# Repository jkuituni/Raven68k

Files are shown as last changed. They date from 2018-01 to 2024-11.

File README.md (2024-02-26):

# Raven68k
Raven 68k is a simple Motorola 68k family based single board computer. The machine will serve as a learning tool
for building a 68k based machines for learning on how to interface various chips and add on expansions for the
architecture. It is also aimed to be a platform for learning on how to write firmware and operating system level
code and how to implement the required logic in VHDL code to tie in all of the functionality required. We are
interested on eventually getting Linux up and running on the hardware as the Linux/m68k is still maintained and
it supports many of the basic building blocks.

The project will be documented to a blog along with datasheets of all the components used.

## Folder Structure
*datasheets/* -- The datasheets of the components used in various revisions of Raven.

*firmware/* - ROM images to boot and initialize the system.

*software/* - S68 programs that can be loaded from the firmware. Many of these are built with [EASy68k](http://easy68k.com/).

*hardware/* -- KiCAD schematics and other files as well as VHDL code for the CPLD are located here.

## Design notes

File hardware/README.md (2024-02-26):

# Raven68k - Hardware

Hardware description for the various revisions are contained with-in here. Each directory contains the KiCAD schematic files as well as other KiCAD files. You will also find revision specific Xilinx VHDL files required for programing the CPLD chips under the directories.

## Folder structure

*prototype/* - Prototype schematics.

*rev1/* - Files for revision 1.

*rev2/* - Files for revision 2.

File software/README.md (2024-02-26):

# Raven68k - Software

Software for Raven. Common for all Raven revisions.

## Folder structure

*ehbasic/* - Port of Lee Davison's excellent EHBASIC for Raven.

*interrupt-monitor/* - Interrupt driven machine language monitor by Hayden Kroepfl ported to run on Raven.

*polling-monitor/* - A polling version of the above.

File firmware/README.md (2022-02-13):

# How to compile
### The short, short version

 1. Get `docker`. Actually, get `nerdctl` or `podman` instead if you know what you are doing.
 2. Pull the compiler container

> docker pull mrszb/m68kcross:11.2

3. From this directory, start the container and mount this directory as `/src`

> docker run --rm -it -v ${PWD}:/src mrszb/m68kcross:11.2 bash

The source is now mounted to the `/src` folder.  To compile:

> cd /src
> make clean
> make

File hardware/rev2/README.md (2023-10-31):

# Raven68k - Revision 2

The specifications for the revision 2 version of Raven68k are as follows:

- Motorola 68010 CPU
- 64kB of EEPROM for bootstrapping the Linux
- Single 72pin SIMM socket for RAM. Upto 16MB supported.
- Motorola 68681 DUART with USB adapter on one UART and max233 on other
- Dallas DS12887A Real Time Clock
- Xilinx XC9572XL CPLD as system glue logic.

The revision 2 of Raven is intended as a minor improvement and bug fix version. Most likely no further revisions will be made and work will continue in a higher spec follow-up computer.

## Folder structure

*schematic/* - KiCad schematics for this revision.

*vhdl/* - The VHDL source for the CPLD that manages most of the TTL logic present and implements the DRAM controller. 

*xilinx/* - The ISE WebPack (14.2) project itself, which targets a QFP100 XC9572XL.

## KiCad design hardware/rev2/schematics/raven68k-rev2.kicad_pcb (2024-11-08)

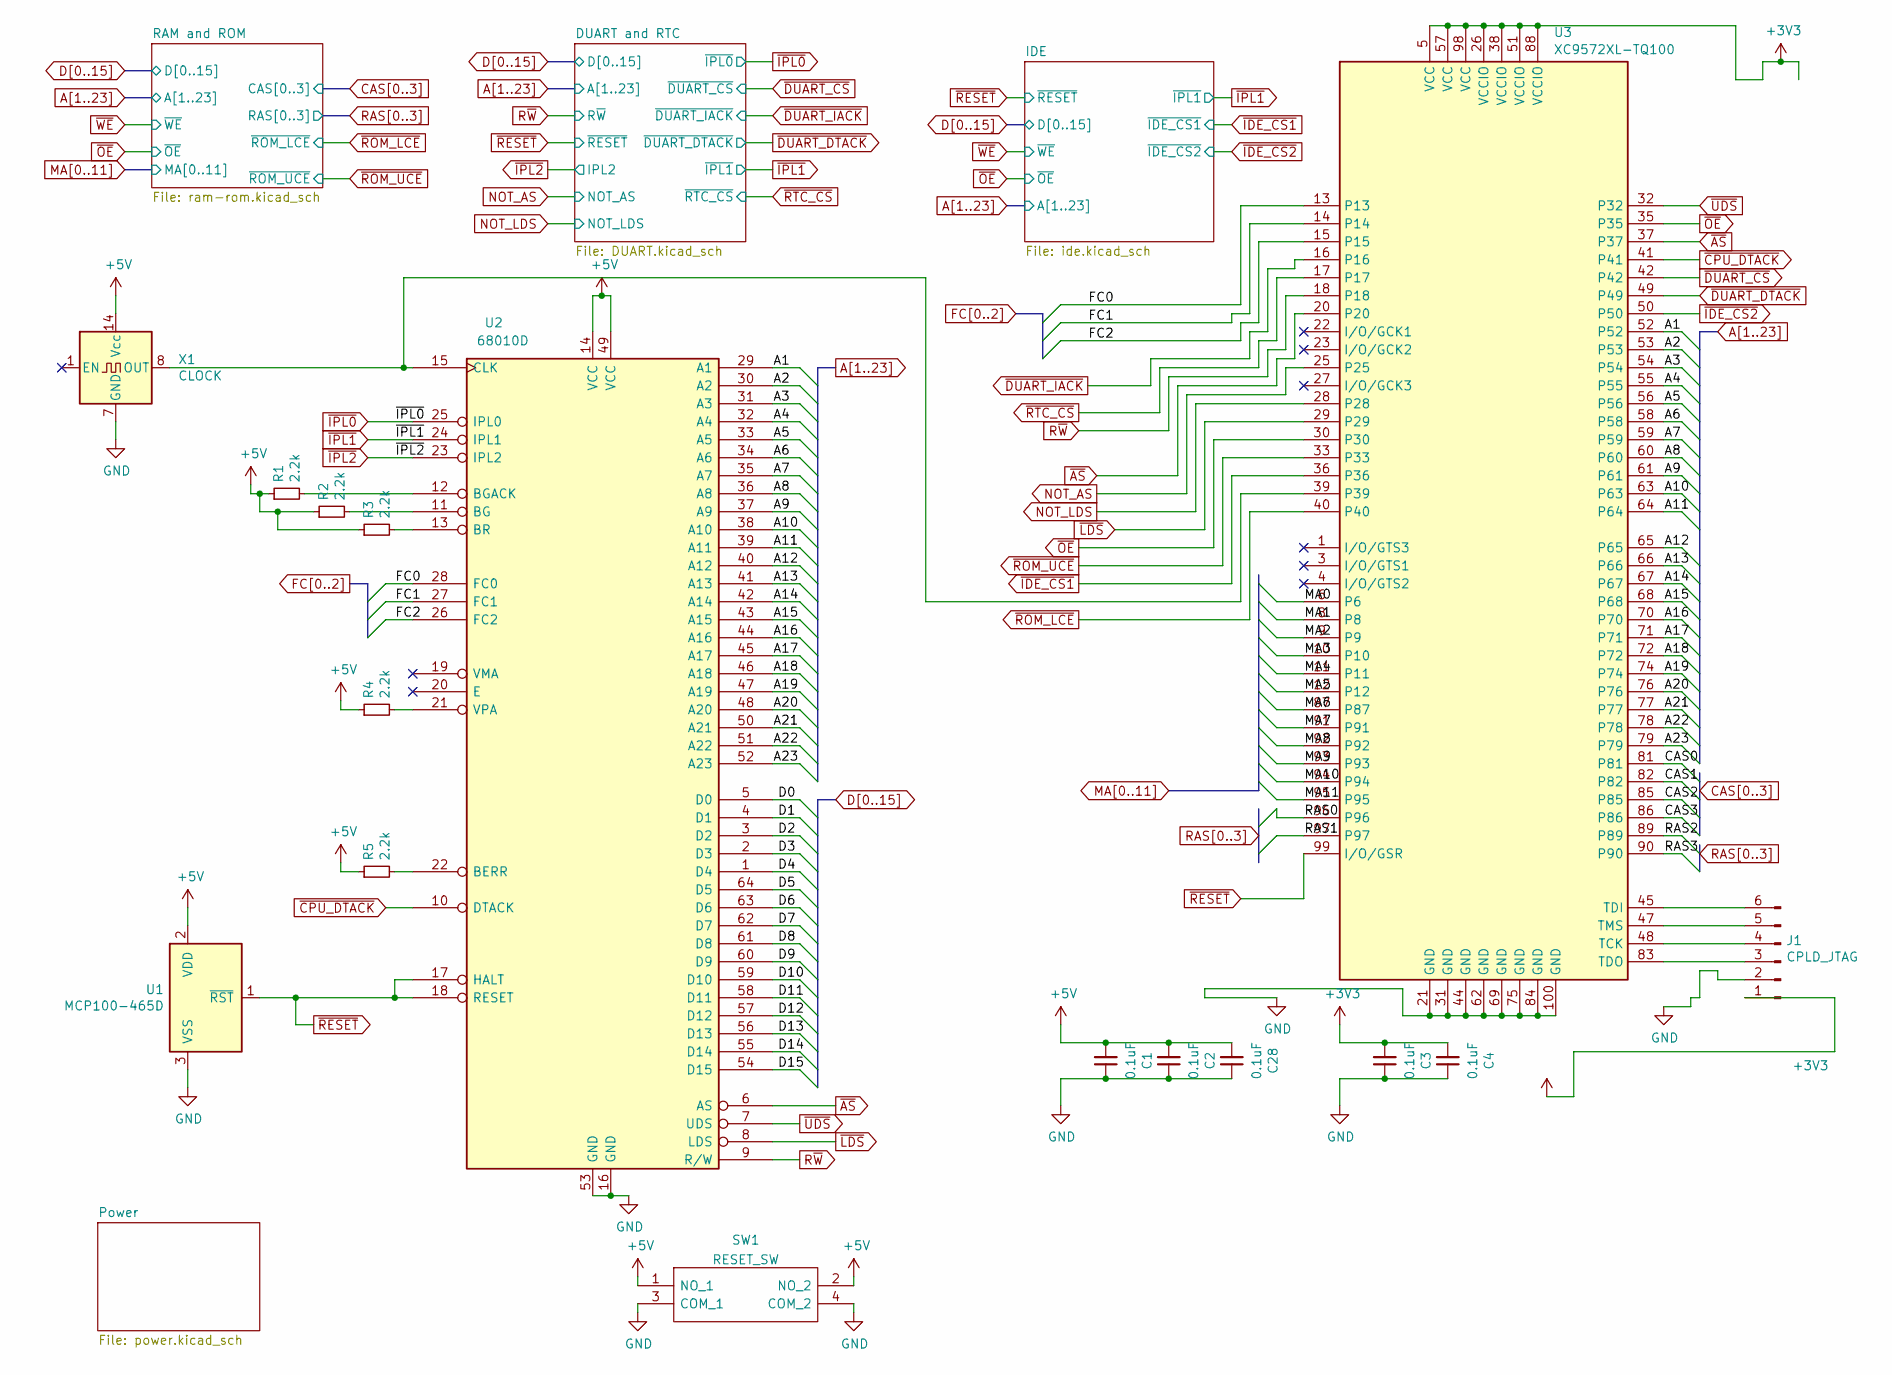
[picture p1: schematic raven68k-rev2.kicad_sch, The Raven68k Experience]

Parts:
C1, C2, C3, C4, C28: 0.1uF; C_1206_3216Metric_Pad1.33x1.80mm_HandSolder; LCSC C24497
J1: CPLD_JTAG; PinHeader_1x06_P2.54mm_Vertical
R1, R2, R3, R4, R5: 2.2k; R_1206_3216Metric_Pad1.30x1.75mm_HandSolder
SW1: RESET_SW; TS0266170BK160SCRD; Manufacturer_Part_Number TS02-66-170-BK-160-SCR-D
U1: MCP100-465D; TO-92L_HandSolder
U2: 68010D; DIP-64_W25.4mm_Socket_LongPads
U3: XC9572XL-TQ100; TQFP-100_14x14mm_P0.5mm
X1: CLOCK; Oscillator_DIP-14_LargePads

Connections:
+3V3: C3.2, C4.2, J1.1, U3.5 (VCC), U3.26 (VCCIO), U3.38 (VCCIO), U3.51 (VCCIO), U3.57 (VCC), U3.88 (VCCIO), U3.98 (VCC); also elsewhere on the board
+5V: C1.2, C2.2, C28.2, R1.1, R2.1, R3.1, R4.1, R5.1, SW1.1 (NO_1), SW1.2 (NO_2), U1.2 (VDD), U2.14 (VCC), U2.49 (VCC), X1.14 (Vcc); also elsewhere on the board
A1: U2.29 (A1), U3.52; also elsewhere on the board
A2: U2.30 (A2), U3.53; also elsewhere on the board
A3: U2.31 (A3), U3.54; also elsewhere on the board
A4: U2.32 (A4), U3.55; also elsewhere on the board
A5: U2.33 (A5), U3.56; also elsewhere on the board
A6: U2.34 (A6), U3.58; also elsewhere on the board
A7: U2.35 (A7), U3.59; also elsewhere on the board
A8: U2.36 (A8), U3.60; also elsewhere on the board
A9: U2.37 (A9), U3.61; also elsewhere on the board
A10: U2.38 (A10), U3.63; also elsewhere on the board
A11: U2.39 (A11), U3.64; also elsewhere on the board
A12: U2.40 (A12), U3.65; also elsewhere on the board
A13: U2.41 (A13), U3.66; also elsewhere on the board
A14: U2.42 (A14), U3.67; also elsewhere on the board
A15: U2.43 (A15), U3.68; also elsewhere on the board
A16: U2.44 (A16), U3.70
A17: U2.45 (A17), U3.71
A18: U2.46 (A18), U3.72
A19: U2.47 (A19), U3.74
A20: U2.48 (A20), U3.76
A21: U2.50 (A21), U3.77
A22: U2.51 (A22), U3.78
A23: U2.52 (A23), U3.79
CAS0: U3.81; also elsewhere on the board
CAS1: U3.82; also elsewhere on the board
CAS2: U3.85; also elsewhere on the board
CAS3: U3.86; also elsewhere on the board
D0: U2.5 (D0); also elsewhere on the board
D1: U2.4 (D1); also elsewhere on the board
D2: U2.3 (D2); also elsewhere on the board
D3: U2.2 (D3); also elsewhere on the board
D4: U2.1 (D4); also elsewhere on the board
D5: U2.64 (D5); also elsewhere on the board
D6: U2.63 (D6); also elsewhere on the board
D7: U2.62 (D7); also elsewhere on the board
D8: U2.61 (D8); also elsewhere on the board
D9: U2.60 (D9); also elsewhere on the board
D10: U2.59 (D10); also elsewhere on the board
D11: U2.58 (D11); also elsewhere on the board
D12: U2.57 (D12); also elsewhere on the board
D13: U2.56 (D13); also elsewhere on the board
D14: U2.55 (D14); also elsewhere on the board
D15: U2.54 (D15); also elsewhere on the board
FC0: U2.28 (FC0), U3.13
FC1: U2.27 (FC1), U3.14
FC2: U2.26 (FC2), U3.15
GND: C1.1, C2.1, C3.1, C4.1, C28.1, J1.2, SW1.3 (COM_1), SW1.4 (COM_2), U1.3 (VSS), U2.16 (GND), U2.53 (GND), U3.21 (GND), U3.31 (GND), U3.44 (GND), U3.62 (GND), U3.69 (GND), U3.75 (GND), U3.84 (GND), U3.100 (GND), X1.7 (GND); also elsewhere on the board
MA0: U3.6; also elsewhere on the board
MA1: U3.8; also elsewhere on the board
MA2: U3.9; also elsewhere on the board
MA3: U3.10; also elsewhere on the board
MA4: U3.11; also elsewhere on the board
MA5: U3.12; also elsewhere on the board
MA6: U3.87; also elsewhere on the board
MA7: U3.91; also elsewhere on the board
MA8: U3.92; also elsewhere on the board
MA9: U3.93; also elsewhere on the board
MA10: U3.94; also elsewhere on the board
MA11: U3.95; also elsewhere on the board
NOT_AS: U3.25; also elsewhere on the board
NOT_LDS: U3.28; also elsewhere on the board
unnamed: J1.3, U3.83 (TDO)
unnamed: J1.4, U3.48 (TCK)
unnamed: J1.5, U3.47 (TMS)
unnamed: J1.6, U3.45 (TDI)
unnamed: R5.2, U2.22 (BERR)
unnamed: R2.2, U2.11 (BG)
unnamed: R1.2, U2.12 (BGACK)
unnamed: R3.2, U2.13 (BR)
unnamed: U2.15 (CLK), U3.39, X1.8 (OUT)
unnamed: R4.2, U2.21 (VPA)
RAS0: U3.96; also elsewhere on the board
RAS1: U3.97; also elsewhere on the board
RAS2: U3.89; also elsewhere on the board
RAS3: U3.90; also elsewhere on the board
R~W: U2.9 (R/W), U3.18; also elsewhere on the board
~AS: U2.6 (AS), U3.20, U3.37
~CPU_DTACK: U2.10 (DTACK), U3.41
~DUART_CS: U3.42; also elsewhere on the board
~DUART_DTACK: U3.49; also elsewhere on the board
~DUART_IACK: U3.16; also elsewhere on the board
~IDE_CS1: U3.36; also elsewhere on the board
~IDE_CS2: U3.50; also elsewhere on the board
~IPL0: U2.25 (IPL0); also elsewhere on the board
~IPL1: U2.24 (IPL1); also elsewhere on the board
~IPL2: U2.23 (IPL2); also elsewhere on the board
~LDS: U2.8 (LDS), U3.29
~OE: U3.30, U3.35; also elsewhere on the board
~RESET: U1.1 (~RST), U2.17 (HALT), U2.18 (RESET), U3.99 (I/O/GSR); also elsewhere on the board
~ROM_LCE: U3.40; also elsewhere on the board
~ROM_UCE: U3.33; also elsewhere on the board
~RTC_CS: U3.17; also elsewhere on the board
~UDS: U2.7 (UDS), U3.32

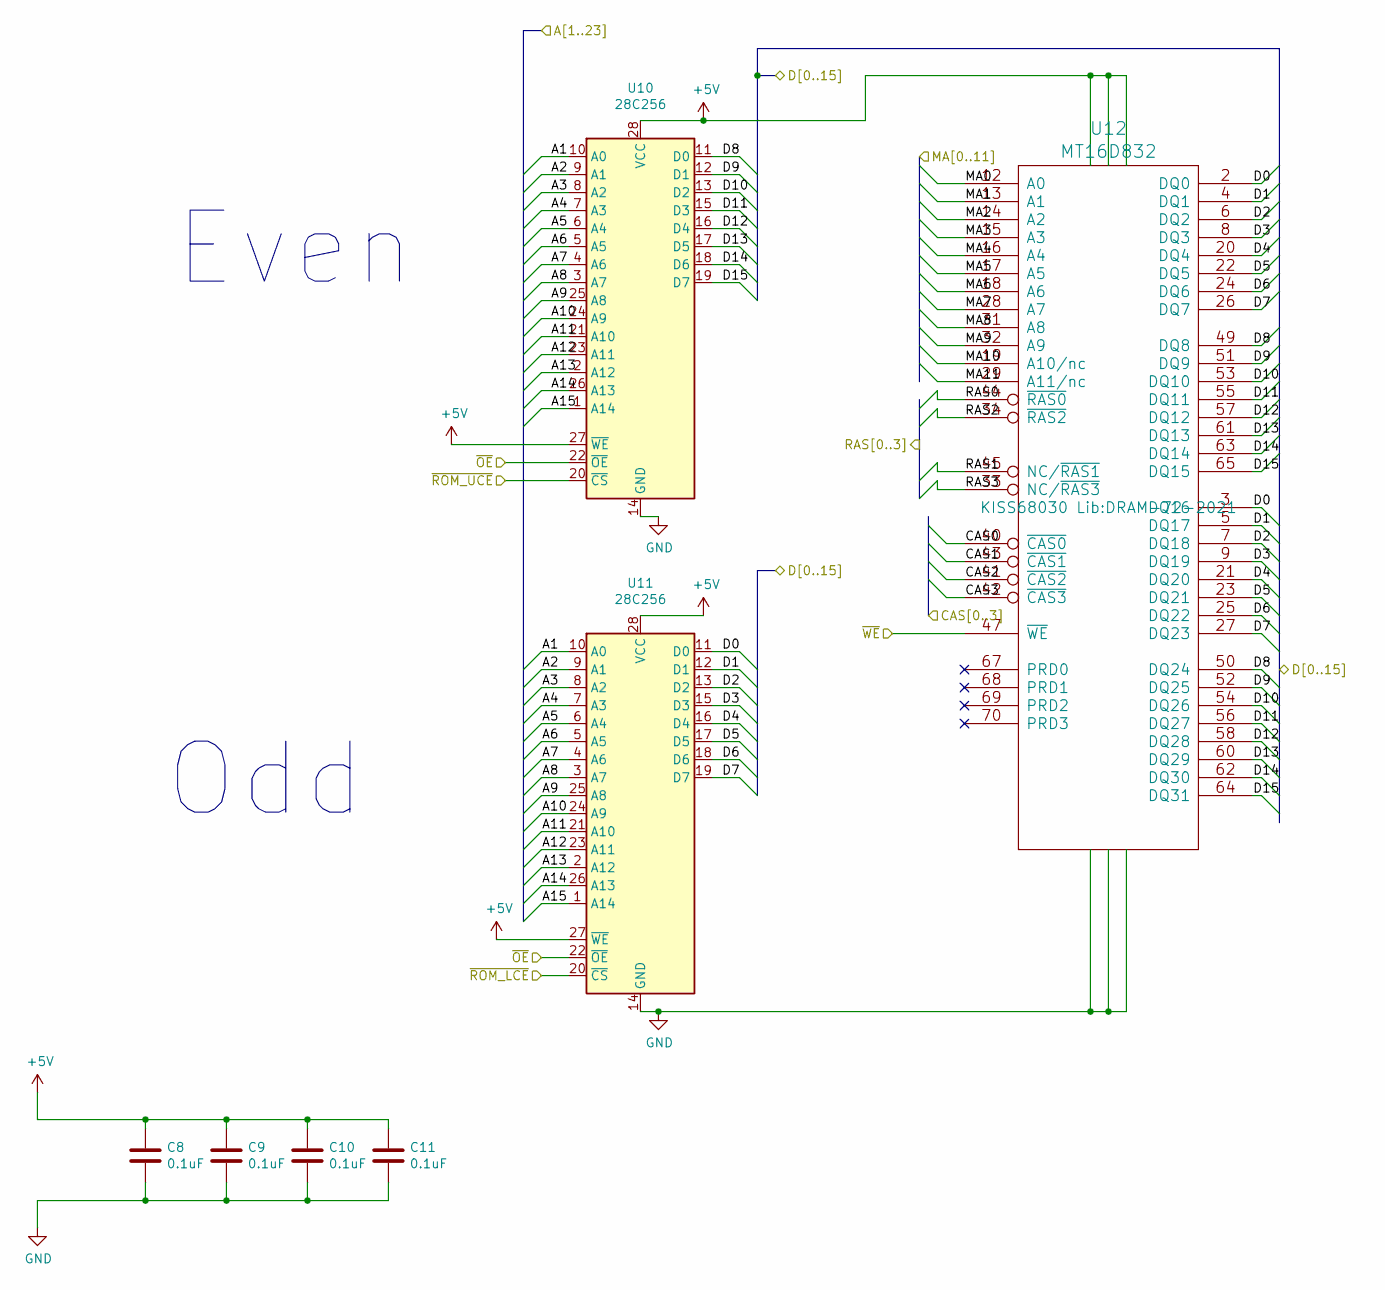
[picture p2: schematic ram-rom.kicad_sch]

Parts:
C8, C9, C10, C11: 0.1uF; C_1206_3216Metric_Pad1.33x1.80mm_HandSolder; LCSC C24497
U10, U11: 28C256; DIP-28_W15.24mm_Socket_LongPads
U12: MT16D832; DRAM-72-2021

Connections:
+5V: C8.1, C9.1, C10.1, C11.1, U10.27 (~WE), U10.28 (VCC), U11.27 (~WE), U11.28 (VCC), U12.10 (VCC), U12.30 (VCC), U12.59 (VCC); also elsewhere on the board
A1: U10.10 (A0), U11.10 (A0); also elsewhere on the board
A2: U10.9 (A1), U11.9 (A1); also elsewhere on the board
A3: U10.8 (A2), U11.8 (A2); also elsewhere on the board
A4: U10.7 (A3), U11.7 (A3); also elsewhere on the board
A5: U10.6 (A4), U11.6 (A4); also elsewhere on the board
A6: U10.5 (A5), U11.5 (A5); also elsewhere on the board
A7: U10.4 (A6), U11.4 (A6); also elsewhere on the board
A8: U10.3 (A7), U11.3 (A7); also elsewhere on the board
A9: U10.25 (A8), U11.25 (A8); also elsewhere on the board
A10: U10.24 (A9), U11.24 (A9); also elsewhere on the board
A11: U10.21 (A10), U11.21 (A10); also elsewhere on the board
A12: U10.23 (A11), U11.23 (A11); also elsewhere on the board
A13: U10.2 (A12), U11.2 (A12); also elsewhere on the board
A14: U10.26 (A13), U11.26 (A13); also elsewhere on the board
A15: U10.1 (A14), U11.1 (A14); also elsewhere on the board
CAS0: U12.40 (~CAS0); also elsewhere on the board
CAS1: U12.43 (~CAS1); also elsewhere on the board
CAS2: U12.41 (~CAS2); also elsewhere on the board
CAS3: U12.42 (~CAS3); also elsewhere on the board
D0: U11.11 (D0), U12.2 (DQ0), U12.3 (DQ16); also elsewhere on the board
D1: U11.12 (D1), U12.4 (DQ1), U12.5 (DQ17); also elsewhere on the board
D2: U11.13 (D2), U12.6 (DQ2), U12.7 (DQ18); also elsewhere on the board
D3: U11.15 (D3), U12.8 (DQ3), U12.9 (DQ19); also elsewhere on the board
D4: U11.16 (D4), U12.20 (DQ4), U12.21 (DQ20); also elsewhere on the board
D5: U11.17 (D5), U12.22 (DQ5), U12.23 (DQ21); also elsewhere on the board
D6: U11.18 (D6), U12.24 (DQ6), U12.25 (DQ22); also elsewhere on the board
D7: U11.19 (D7), U12.26 (DQ7), U12.27 (DQ23); also elsewhere on the board
D8: U10.11 (D0), U12.49 (DQ8), U12.50 (DQ24); also elsewhere on the board
D9: U10.12 (D1), U12.51 (DQ9), U12.52 (DQ25); also elsewhere on the board
D10: U10.13 (D2), U12.53 (DQ10), U12.54 (DQ26); also elsewhere on the board
D11: U10.15 (D3), U12.55 (DQ11), U12.56 (DQ27); also elsewhere on the board
D12: U10.16 (D4), U12.57 (DQ12), U12.58 (DQ28); also elsewhere on the board
D13: U10.17 (D5), U12.60 (DQ29), U12.61 (DQ13); also elsewhere on the board
D14: U10.18 (D6), U12.62 (DQ30), U12.63 (DQ14); also elsewhere on the board
D15: U10.19 (D7), U12.64 (DQ31), U12.65 (DQ15); also elsewhere on the board
GND: C8.2, C9.2, C10.2, C11.2, U10.14 (GND), U11.14 (GND), U12.1 (GND), U12.39 (GND), U12.72 (GND); also elsewhere on the board
MA0: U12.12 (A0); also elsewhere on the board
MA1: U12.13 (A1); also elsewhere on the board
MA2: U12.14 (A2); also elsewhere on the board
MA3: U12.15 (A3); also elsewhere on the board
MA4: U12.16 (A4); also elsewhere on the board
MA5: U12.17 (A5); also elsewhere on the board
MA6: U12.18 (A6); also elsewhere on the board
MA7: U12.28 (A7); also elsewhere on the board
MA8: U12.31 (A8); also elsewhere on the board
MA9: U12.32 (A9); also elsewhere on the board
MA10: U12.19 (A10/nc); also elsewhere on the board
MA11: U12.29 (A11/nc); also elsewhere on the board
RAS0: U12.44 (~RAS0); also elsewhere on the board
RAS1: U12.45 (NC/~RAS1); also elsewhere on the board
RAS2: U12.34 (~RAS2); also elsewhere on the board
RAS3: U12.33 (NC/~RAS3); also elsewhere on the board
~OE: U10.22 (~OE), U11.22 (~OE); also elsewhere on the board
~ROM_LCE: U11.20 (~CS); also elsewhere on the board
~ROM_UCE: U10.20 (~CS); also elsewhere on the board
~WE: U12.47 (~WE); also elsewhere on the board

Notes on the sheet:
Even
Odd

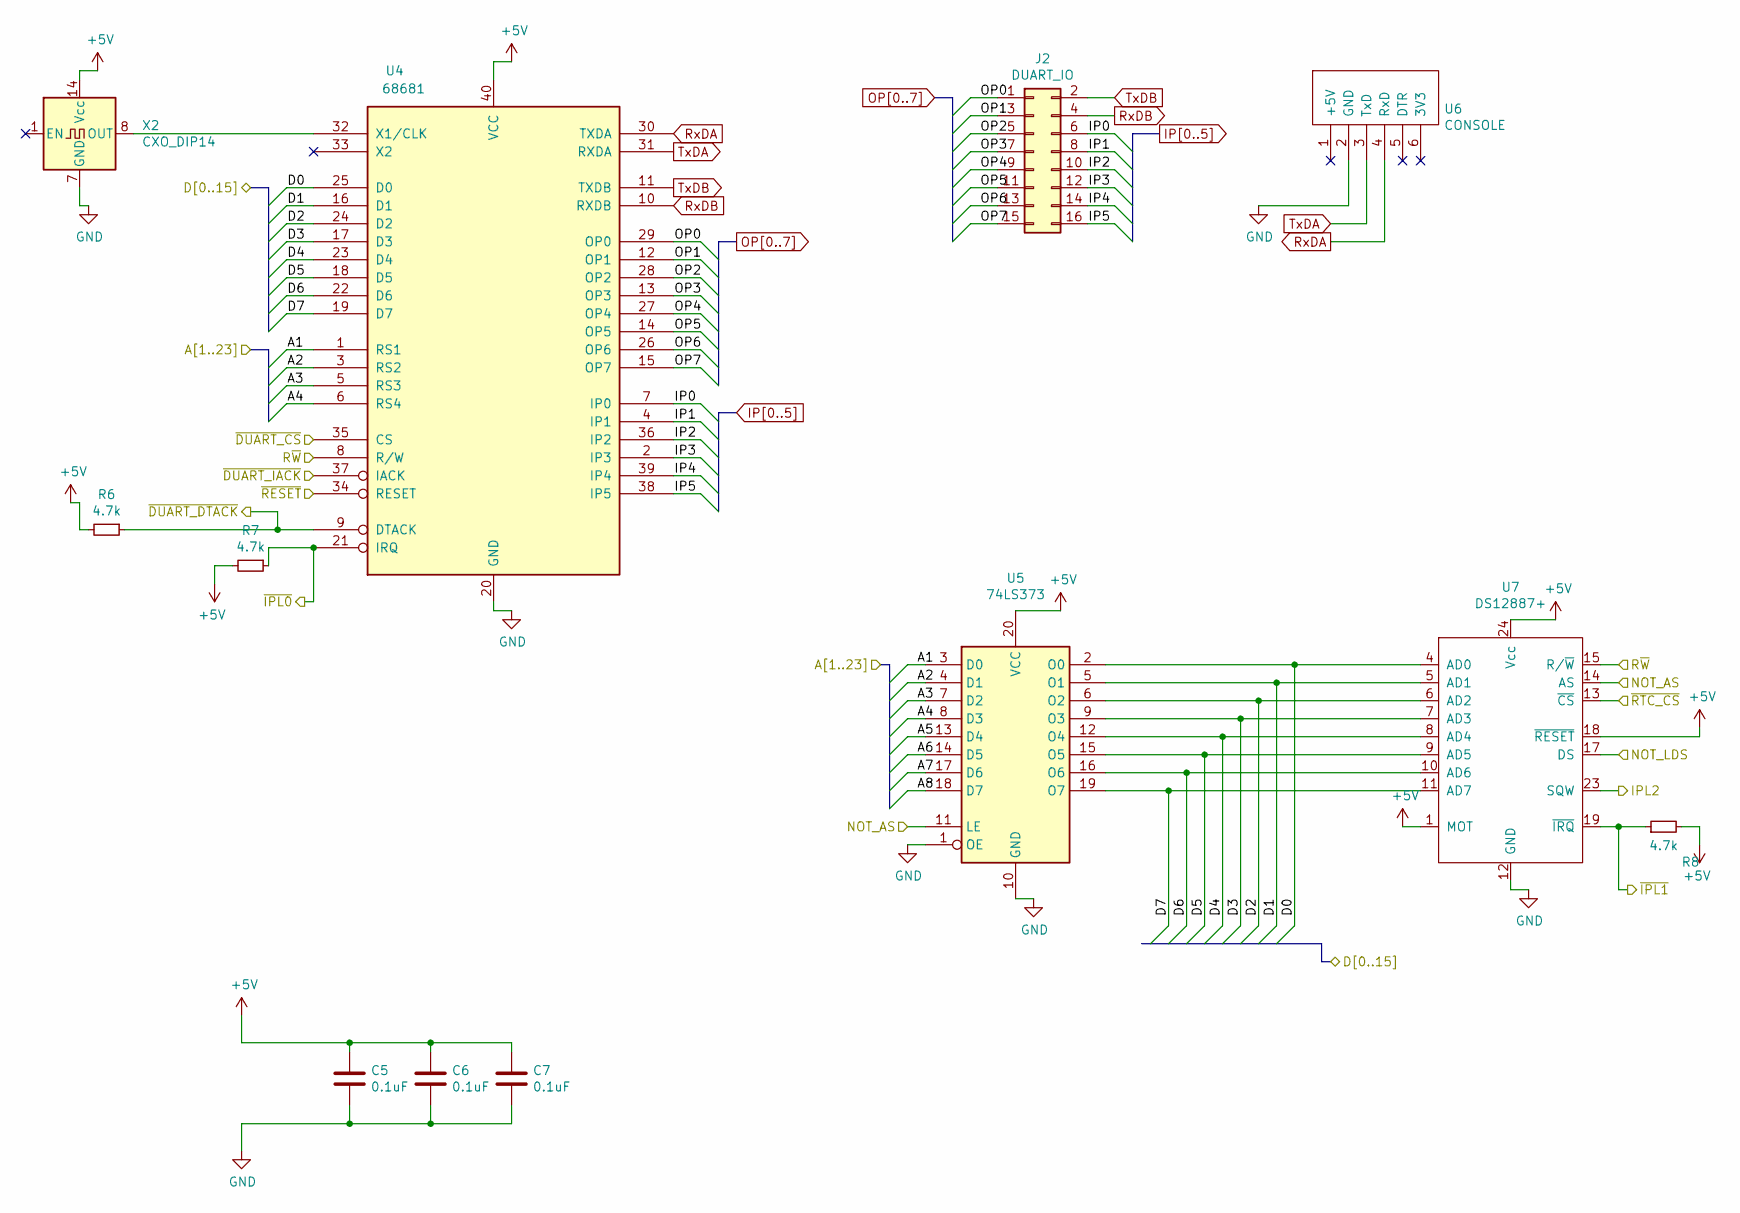
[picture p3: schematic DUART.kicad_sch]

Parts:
C5, C6, C7: 0.1uF; C_1206_3216Metric_Pad1.33x1.80mm_HandSolder; LCSC C24497
J2: DUART_IO; PinHeader_2x08_P2.54mm_Vertical
R6, R7, R8: 4.7k; R_1206_3216Metric_Pad1.30x1.75mm_HandSolder
U4: 68681; DIP-40_W25.4mm_Socket_LongPads
U5: 74LS373; DIP-20_W7.62mm_Socket_LongPads
U6: CONSOLE; PinHeader_1x06_P2.54mm_Vertical
U7: DS12887+; DIP-24_W15.24mm_Socket_LongPads
X2: CXO_DIP14; Oscillator_DIP-14_LargePads

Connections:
+5V: C5.1, C6.1, C7.1, R6.2, R7.2, R8.2, U4.40 (VCC), U5.20 (VCC), U7.1 (MOT), U7.18 (~RESET), U7.24 (Vcc), X2.14 (Vcc); also elsewhere on the board
A1: U4.1 (RS1), U5.3 (D0); also elsewhere on the board
A2: U4.3 (RS2), U5.4 (D1); also elsewhere on the board
A3: U4.5 (RS3), U5.7 (D2); also elsewhere on the board
A4: U4.6 (RS4), U5.8 (D3); also elsewhere on the board
A5: U5.13 (D4); also elsewhere on the board
A6: U5.14 (D5); also elsewhere on the board
A7: U5.17 (D6); also elsewhere on the board
A8: U5.18 (D7); also elsewhere on the board
D0: U4.25 (D0), U5.2 (O0), U7.4 (AD0); also elsewhere on the board
D1: U4.16 (D1), U5.5 (O1), U7.5 (AD1); also elsewhere on the board
D2: U4.24 (D2), U5.6 (O2), U7.6 (AD2); also elsewhere on the board
D3: U4.17 (D3), U5.9 (O3), U7.7 (AD3); also elsewhere on the board
D4: U4.23 (D4), U5.12 (O4), U7.8 (AD4); also elsewhere on the board
D5: U4.18 (D5), U5.15 (O5), U7.9 (AD5); also elsewhere on the board
D6: U4.22 (D6), U5.16 (O6), U7.10 (AD6); also elsewhere on the board
D7: U4.19 (D7), U5.19 (O7), U7.11 (AD7); also elsewhere on the board
GND: C5.2, C6.2, C7.2, U4.20 (GND), U5.1 (OE), U5.10 (GND), U6.2 (GND), U7.12 (GND), X2.7 (GND); also elsewhere on the board
IP0: J2.6, U4.7 (IP0)
IP1: J2.8, U4.4 (IP1)
IP2: J2.10, U4.36 (IP2)
IP3: J2.12, U4.2 (IP3)
IP4: J2.14, U4.39 (IP4)
IP5: J2.16, U4.38 (IP5)
NOT_AS: U5.11 (LE), U7.14 (AS); also elsewhere on the board
NOT_LDS: U7.17 (DS); also elsewhere on the board
unnamed: U4.32 (X1/CLK), X2.8 (OUT)
OP0: J2.1, U4.29 (OP0)
OP1: J2.3, U4.12 (OP1)
OP2: J2.5, U4.28 (OP2)
OP3: J2.7, U4.13 (OP3)
OP4: J2.9, U4.27 (OP4)
OP5: J2.11, U4.14 (OP5)
OP6: J2.13, U4.26 (OP6)
OP7: J2.15, U4.15 (OP7)
RxDA: U4.30 (TXDA), U6.4 (RxD)
RxDB: J2.4, U4.10 (RXDB)
R~W: U4.8 (R/W), U7.15 (R/~W); also elsewhere on the board
TxDA: U4.31 (RXDA), U6.3 (TxD)
TxDB: J2.2, U4.11 (TXDB)
~DUART_CS: U4.35 (CS); also elsewhere on the board
~DUART_DTACK: R6.1, U4.9 (DTACK); also elsewhere on the board
~DUART_IACK: U4.37 (IACK); also elsewhere on the board
~IPL0: R7.1, U4.21 (IRQ); also elsewhere on the board
~IPL1: R8.1, U7.19 (~IRQ); also elsewhere on the board
~IPL2: U7.23 (SQW); also elsewhere on the board
~RESET: U4.34 (RESET); also elsewhere on the board
~RTC_CS: U7.13 (~CS); also elsewhere on the board

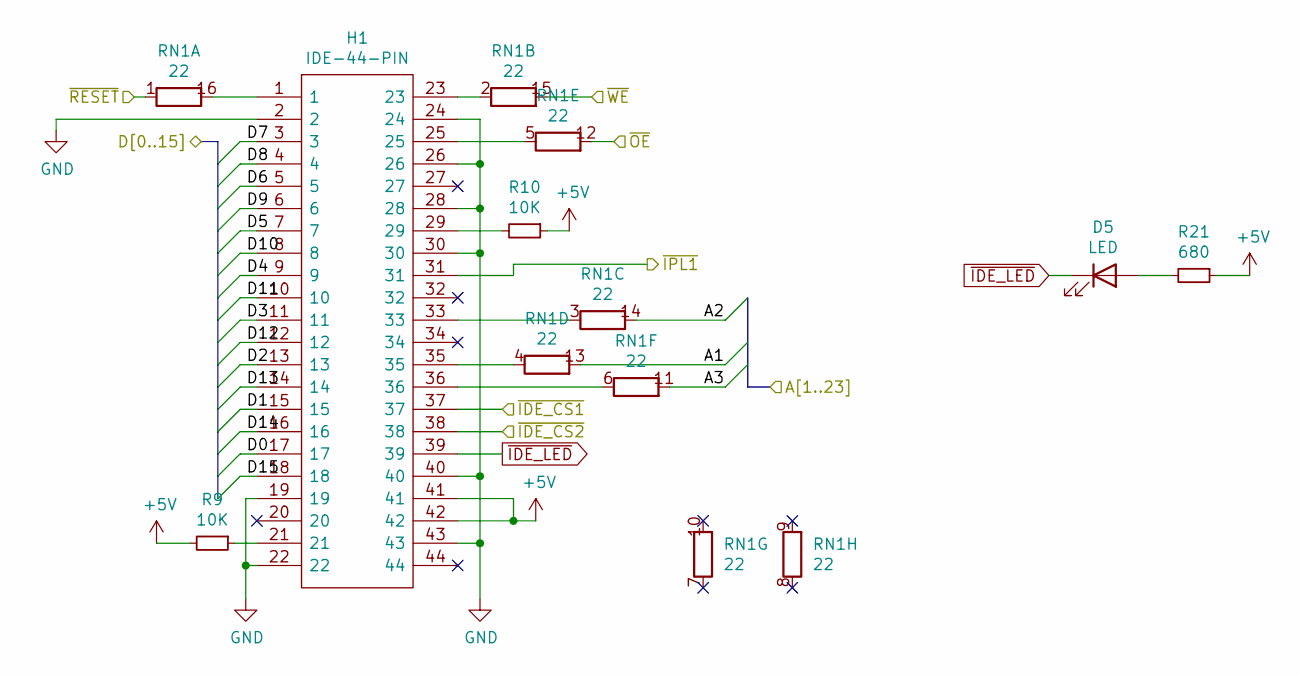
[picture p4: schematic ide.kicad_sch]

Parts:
D5: LED; LED_D3.0mm
H1: IDE-44-PIN; SHDR44W55P200_2X22_4665X630X640P; Manufacturer_Part_Number 57102-G06-22LF
R9, R10: 10K; R_1206_3216Metric_Pad1.30x1.75mm_HandSolder
R21: 680; R_1206_3216Metric_Pad1.30x1.75mm_HandSolder
RN1: 22; DIP-16_W7.62mm_Socket_LongPads

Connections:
+5V: H1.41, H1.42, R9.2, R10.1, R21.1; also elsewhere on the board
A1: RN1.13 (R4.2); also elsewhere on the board
A2: RN1.14 (R3.2); also elsewhere on the board
A3: RN1.11 (R6.2); also elsewhere on the board
D0: H1.17; also elsewhere on the board
D1: H1.15; also elsewhere on the board
D2: H1.13; also elsewhere on the board
D3: H1.11; also elsewhere on the board
D4: H1.9; also elsewhere on the board
D5: H1.7; also elsewhere on the board
D6: H1.5; also elsewhere on the board
D7: H1.3; also elsewhere on the board
D8: H1.4; also elsewhere on the board
D9: H1.6; also elsewhere on the board
D10: H1.8; also elsewhere on the board
D11: H1.10; also elsewhere on the board
D12: H1.12; also elsewhere on the board
D13: H1.14; also elsewhere on the board
D14: H1.16; also elsewhere on the board
D15: H1.18; also elsewhere on the board
GND: H1.2, H1.19, H1.22, H1.24, H1.26, H1.28, H1.30, H1.40, H1.43; also elsewhere on the board
unnamed: D5.2 (A), R21.2
unnamed: H1.21, R9.1
unnamed: H1.29, R10.2
unnamed: H1.1, RN1.16 (R1.2)
unnamed: H1.23, RN1.2 (R2.1)
unnamed: H1.33, RN1.3 (R3.1)
unnamed: H1.35, RN1.4 (R4.1)
unnamed: H1.25, RN1.5 (R5.1)
unnamed: H1.36, RN1.6 (R6.1)
~IDE_CS1: H1.37; also elsewhere on the board
~IDE_CS2: H1.38; also elsewhere on the board
~IDE_LED: D5.1 (K), H1.39
~IPL1: H1.31; also elsewhere on the board
~OE: RN1.12 (R5.2); also elsewhere on the board
~RESET: RN1.1 (R1.1); also elsewhere on the board
~WE: RN1.15 (R2.2); also elsewhere on the board

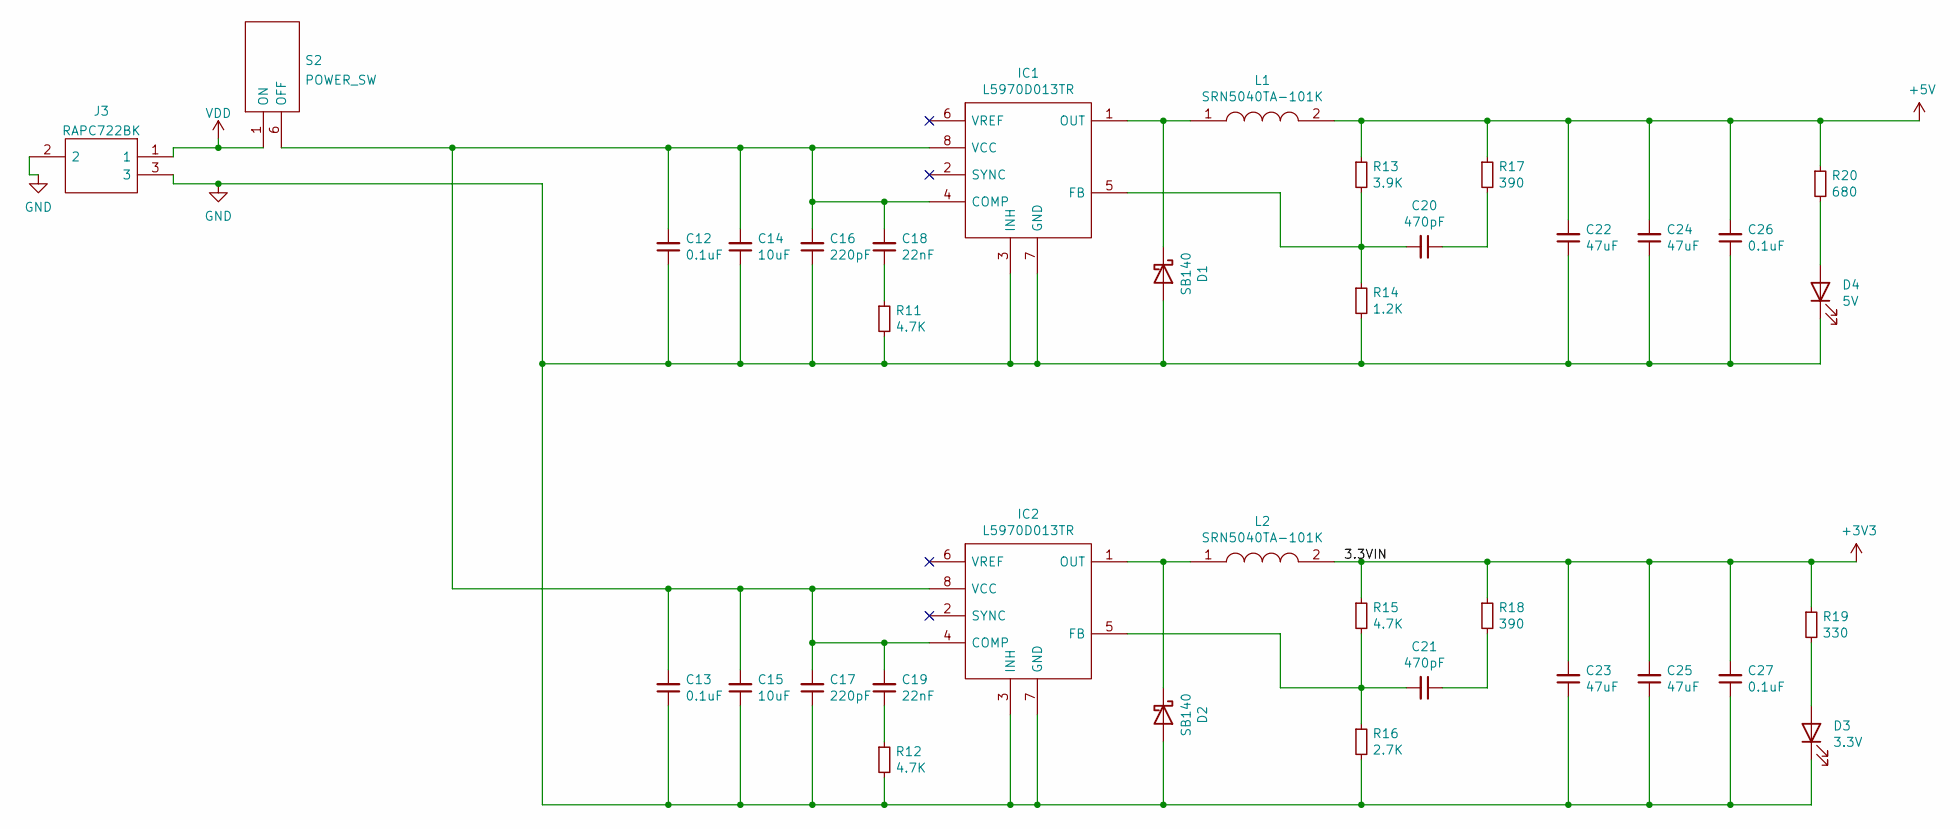
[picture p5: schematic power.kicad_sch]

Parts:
C12, C13, C26, C27: 0.1uF; C_1206_3216Metric_Pad1.33x1.80mm_HandSolder; LCSC C24497
C14, C15: 10uF; C_1206_3216Metric_Pad1.33x1.80mm_HandSolder; LCSC C13585
C16, C17: 220pF; C_1206_3216Metric_Pad1.33x1.80mm_HandSolder; LCSC C1854
C18, C19: 22nF; C_1206_3216Metric_Pad1.33x1.80mm_HandSolder; LCSC C97929
C20, C21: 470pF; C_1206_3216Metric_Pad1.33x1.80mm_HandSolder; LCSC C1868
C22, C23, C24, C25: 47uF; C_1206_3216Metric_Pad1.33x1.80mm_HandSolder
D1, D2: SB140; D_1206_3216Metric_Pad1.42x1.75mm_HandSolder
D3: 3.3V; LED_D3.0mm
D4: 5V; LED_D3.0mm
IC1, IC2: L5970D013TR; SO-8_5.3x6.2mm_P1.27mm; Manufacturer_Part_Number L5970D013TR; Mouser Part Number 511-L5970D013TR
J3: RAPC722BK; Manufacturer_Part_Number RAPC722BK; Mouser Part Number 502-RAPC722BK
L1, L2: SRN5040TA-101K; SRN5040TA101K; Manufacturer_Part_Number SRN5040TA-101K; Mouser Part Number 652-SRN5040TA-101K
R11, R12: 4.7K; R_1206_3216Metric_Pad1.30x1.75mm_HandSolder; LCSC C17936
R13: 3.9K; R_1206_3216Metric_Pad1.30x1.75mm_HandSolder
R14: 1.2K; R_1206_3216Metric_Pad1.30x1.75mm_HandSolder
R15: 4.7K; R_1206_3216Metric_Pad1.30x1.75mm_HandSolder
R16: 2.7K; R_1206_3216Metric_Pad1.30x1.75mm_HandSolder
R17, R18: 390; R_1206_3216Metric_Pad1.30x1.75mm_HandSolder
R19: 330; R_1206_3216Metric_Pad1.30x1.75mm_HandSolder
R20: 680; R_1206_3216Metric_Pad1.30x1.75mm_HandSolder
S2: POWER_SW; GPTS203212B; Manufacturer_Part_Number GPTS203212B; Mouser Part Number 629-GPTS203212B

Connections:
+3V3: C23.2, C25.2, C27.2, L2.2, R15.1, R18.1, R19.1; also elsewhere on the board
+5V: C22.2, C24.2, C26.2, L1.2, R13.1, R17.1, R20.1; also elsewhere on the board
GND: C12.1, C13.1, C14.1, C15.1, C16.1, C17.1, C22.1, C23.1, C24.1, C25.1, C26.1, C27.1, D1.2 (A), D2.2 (A), D3.1 (K), D4.1 (K), IC1.3 (INH), IC1.7 (GND), IC2.3 (INH), IC2.7 (GND), J3.2, J3.3, R11.2, R12.2, R14.2, R16.2; also elsewhere on the board
unnamed: C18.1, R11.1
unnamed: C19.1, R12.1
unnamed: C20.1, R17.2
unnamed: C21.1, R18.2
unnamed: D1.1 (K), IC1.1 (OUT), L1.1
unnamed: D2.1 (K), IC2.1 (OUT), L2.1
unnamed: D3.2 (A), R19.2
unnamed: D4.2 (A), R20.2
unnamed: C12.2, C13.2, C14.2, C15.2, C16.2, C17.2, C18.2, C19.2, IC1.4 (COMP), IC1.8 (VCC), IC2.4 (COMP), IC2.8 (VCC), S2.6 (OFF)
unnamed: C20.2, IC1.5 (FB), R13.2, R14.1
unnamed: C21.2, IC2.5 (FB), R15.2, R16.1
VDD: J3.1, S2.1 (ON)

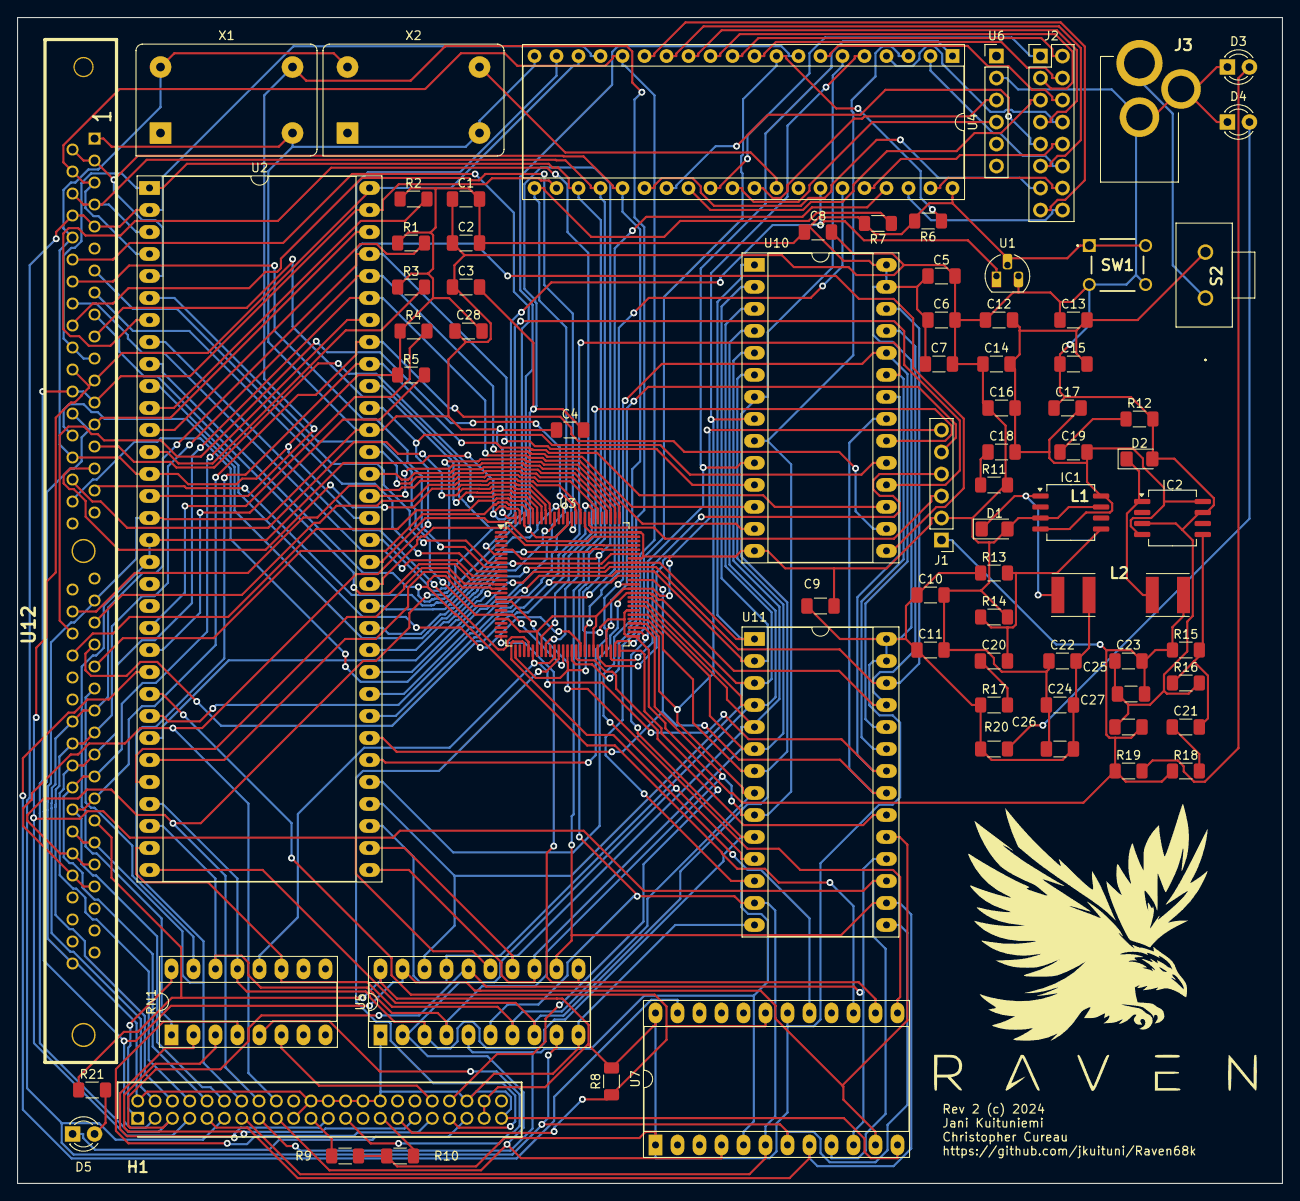
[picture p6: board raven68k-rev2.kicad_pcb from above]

Board: 2 copper layers, 146.0 x 134.6 mm, 77 parts (0 on the bottom side), 137 nets.

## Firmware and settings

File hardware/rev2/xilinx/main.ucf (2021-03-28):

#PACE: Start of Constraints generated by PACE

#PACE: Start of PACE I/O Pin Assignments
NET "ah<20>"  LOC = "P13"  ;
NET "ah<21>"  LOC = "P12"  ;
NET "ah<22>"  LOC = "P8"  ;
NET "ah<23>"  LOC = "P7"  ;
NET "al<1>"  LOC = "P19"  ;
NET "al<2>"  LOC = "P18"  ;
NET "al<3>"  LOC = "P14"  ;
NET "as"  LOC = "P1"  ; 
NET "dtack"  LOC = "P27"  ;
NET "duart_ce"  LOC = "P40"  ;
NET "duart_dtack"  LOC = "P28"  ;
NET "duart_iack"  LOC = "P34"  ;
NET "fc<0>"  LOC = "P5"  ;
NET "fc<1>"  LOC = "P3"  ; 
NET "fc<2>"  LOC = "P2"  ; 
NET "lds"  LOC = "P20"  ;
NET "oe"  LOC = "P33"  ;
NET "ram_lce"  LOC = "P39"  ;
NET "ram_uce"  LOC = "P38"  ;
NET "rom_lce"  LOC = "P37"  ;
NET "rom_uce"  LOC = "P36"  ;
NET "rtc_ce"  LOC = "P42"  ;
NET "rw"  LOC = "P6"  ;
NET "uds"  LOC = "P22"  ;
NET "we"  LOC = "P29"  ;

#PACE: Start of PACE Area Constraints

#PACE: Start of PACE Prohibit Constraints

#PACE: End of Constraints generated by PACE

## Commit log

2018-01-08 Initial commit of Raven 68k schematics in KiCad format. Work-in-progressgit add .
    [Raven68k.sch]
2018-01-09 Added 68681 DUART.
    [Raven68k.sch]
2018-01-09 Added a few pull-down resistors. Continued schematic re-work started in earlier commit.
    [Raven68k.sch]
2018-01-09 Fixed an issue with un-connected address pins a16..a19 and wrong address pin numbering on the RSx register select pins on the 68681.
    [Raven68k.sch]
2018-01-21 replace WE pin with OE = not R/W
2018-01-22 hierarchial sheets
    [Raven68k.kicad_pcb, Raven68k.sch, cpu-logic.sch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]
2018-07-01 first pass at cpld logic. Pins not assigned yet
    [cpld_pad.csv]
2018-07-01 couple of changes
    [cpld_pad.csv]
2018-07-02 release /CS when not needed
    [cpld_pad.csv]
2018-07-02 fix inout signals
    [cpld_pad.csv]
2018-07-02 add component defs
    [cpld_pad.csv]
2018-07-02 final test version
    [cpld_pad.csv]
2018-07-20 begin update for schematic
    [Raven68k.sch, cpu-logic.sch, duart-rtc.sch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]
2018-10-08 kprintf working, IDEATA interface started
    [Raven68k-2018-10-05-20-59-52.sch, Raven68k.sch, cpu-logic-2018-10-05-20-59-52.sch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]
2018-10-10 add prototype
    [file5BD91A8D.sch, raven-prototypes.kicad_pcb, raven-prototypes.sch]
2018-10-11 v1 schematic upates
    [file5BC30D7B.sch, file5BD87B77.sch, file5BD91A8D.sch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]
2018-10-11 finish logic
    [file5BC30D7B.sch, file5BD87B77.sch, file5BD91A8D.sch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]
2018-10-30 optimized logic
    [file5BC30D7B.sch, file5BD87B77.sch, file5BD91A8D.sch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]
2018-11-05 gerbers created, Rev 0 sent to manufacturer
    [file5BC30D7B.sch, file5BD87B77.sch, file5BD91A8D.sch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]
2021-03-09 out with the old, in with the new
    [Raven68k-2018-10-05-20-59-52.sch, Raven68k.kicad_pcb, Raven68k.sch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]
2021-03-25 prepare for schematics for rev1
    [raven68k-rev1.kicad_pcb, raven68k-rev1.sch]
2021-03-26 Adjusted the I/O layout to avoid pins that are not available on the target CPLD dev board. Added handling of ROM overlay at low memory area during reset for 8 clocks and also adjusted memory decoding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
    [main.ucf]
2021-03-28 Still need to work out pins on CPLD
    [DUART.sch, Interrupts.sch, ram-rom.sch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]
2021-03-28 Initial Work-In-Progress draft version of the Firmware code for RAven68k. Contains functions to init the system, init the DUART, run RAM tests and Download & execute Motorola SRecord format binaries 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
2021-03-29 Couple of cleanups and altered ChkRam not to use stack at this point as we do not know whether or not RAM is good so safer not to use it. Instead, stashing the d1 value to d2 for the duration of the 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
2021-03-30 breadboard prototype
    [memdecode.sch, raven68k-proto.kicad_pcb, raven68k-proto.sch]
2022-01-31 update schematic for rev1
    [DUART.sch, Interrupts.sch, ide.sch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]
2022-02-03 added buffers
    [DUART.sch, Interrupts.sch, ide.sch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]
2022-02-06 upgrade to KiCad 6, first shot at layout
    [DUART.kicad_sch, DUART.sch, Interrupts.sch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]
2022-02-06 Removed KiCAD backup files.
2022-02-07 board layout complete, needs verification
    [DUART.kicad_sch, power.kicad_sch, ram-rom.kicad_sch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]
2022-02-07 move components around
    [power.kicad_sch, raven68k-rev1.kicad_pcb, raven68k-rev1.kicad_sch]
2022-02-08 first plot
    [raven68k-rev1-B_Cu.gbl, raven68k-rev1-B_Mask.gbs, raven68k-rev1-B_Paste.gbp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]
2022-02-08 remove tiny leftover traces
    [raven68k-rev1.kicad_pcb]
2022-02-09 some helpful labels
    [DUART.kicad_sch, power.kicad_sch, ram-rom.kicad_sch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]
2022-02-11 add board standoffs
    [raven68k-rev1-B_Cu.gbl, raven68k-rev1-B_Mask.gbs, raven68k-rev1-B_Paste.gbp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]
2022-02-11 additional mounting standoff near pressure area
    [raven68k-rev1-B_Cu.gbl, raven68k-rev1-B_Mask.gbs, raven68k-rev1-B_Paste.gbp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]
2022-02-15 naming update for NOT_LDS
    [DUART.kicad_sch, raven68k-rev1.kicad_sch]
2022-02-16 first test with interrupts
2022-02-17 compile what should be a working interrupt monitor
2022-02-25 bad footprint on rev1
    [raven68k-rev1-B_Cu.gbl, raven68k-rev1-B_Mask.gbs, raven68k-rev1-B_Paste.gbp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]
2022-02-27 add BOM
    [raven68k-rev1-bom.csv]
2023-10-31 Initial commit for Raven rev 2. Changes compared to the rev 1 are replacement of the SRAM memory with a single 72pin SIMM socket and to accommodate the requirement for writing a DRAM controller state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
    [DUART.kicad_sch, DUART.sch, Interrupts.sch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]
2024-02-22 Fixed Bus connections. Added SIMM control connections to the CPLD. Added missing symbols from rev1 library. Cleaned up some SRAM related control signals that are no longer needed.
    [ram-rom.kicad_sch, raven68k-rev2.kicad_pcb, raven68k-rev2.kicad_sch]
2024-02-22 Added hierarchical labels from main sheet to RAM and ROM sheet.
    [ram-rom.kicad_sch, raven68k-rev2.kicad_sch]
2024-02-22 Added upper two bytes to SIMM connection. Updated the PCB at the same time.
    [ram-rom.kicad_sch, raven68k-rev2.kicad_pcb]
2024-02-23 Added SIMM footprint and Raven logo. Did initial PCB component placement and routing using autorouter. Still needs to be checked before ordering PCBs to verify on an actual hardware.
    [ram-rom.kicad_sch, raven68k-rev2.kicad_pcb]
2024-02-26 Re-structure of the repository to better reflect what is common across the revisions and what is not as well as to be perhaps a bit easier to follow what is where.
    [DUART.kicad_sch, DUART.sch, Interrupts.sch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]
2024-02-28 Minor adjustment to add the CLK signal to the CPLD that was forgotten. Re-did the PCB to reflect this change and also edited the component placement a bit.
    [raven68k-rev2.kicad_pcb, raven68k-rev2.kicad_sch]
2024-09-02 DRC fixes.
    [raven68k-rev2.kicad_pcb]
2024-09-02 ERC fixes, part 1
    [DUART.kicad_sch, ide.kicad_sch, power.kicad_sch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]
2024-11-08 ERC fixes part 2. No more errors reported. Re-routed the PCB.
    [ram-rom.kicad_sch, raven68k-rev2.kicad_pcb, raven68k-rev2.kicad_sch]

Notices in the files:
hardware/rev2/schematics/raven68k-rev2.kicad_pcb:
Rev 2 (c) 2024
